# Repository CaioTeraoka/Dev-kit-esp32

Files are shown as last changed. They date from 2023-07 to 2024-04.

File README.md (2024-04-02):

# Dev Kit ESP32
This project is a board that was made with the purpose of being used to create and test simples projects using ESP32 DevKit. It was made to enthusiasts to have a complete board to play and have fun learning about ESP32. 

## Specifications:
**Power** - 5V <br>
**Stackup:**
1. Signal + 3.3V
2. Ground

## Main Components
- ESP32 DevKit <br>
- Buzzer <br>
- LEDs <br>
- Buttons <br>
- RGB LEDs <br>
- SPI Pin Headers <br>
- I2C Pin Headers <br>
- ADC Pin Headers <br>
- DAC Pin Headers <br>
- USART Pin Headers <br>
- PWM Pin Headers <br>

## 3D Model
 <br>


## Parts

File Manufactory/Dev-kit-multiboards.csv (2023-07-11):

Reference | Value | Footprint | LCSC Part Number | Qtd
BUTTON1-BUTTON3 | SW_Push | Button_Switch_SMD:SW_Push_1P1T_NO_6x6mm_H9.5mm | C255812 | 3
BUZZER1 | Buzzer | Buzzer_Beeper:Buzzer_12x9.5RM7.6 | C96222 | 1
C1-C3 | 100n | Capacitor_SMD:C_1206_3216Metric | C377067 | 3
J1, J2 | Conn_01x04_Socket | Connector_PinHeader_2.54mm:PinHeader_1x04_P2.54mm_Vertical | C6332197 | 2
J3, J6, J7, J12, JP1 | -- valores mistos -- | Connector_PinHeader_2.54mm:PinHeader_1x02_P2.54mm_Vertical | C2685144 | 5
J4, J5 | Conn_01x19_Socket | Connector_PinSocket_2.54mm:PinSocket_1x19_P2.54mm_Vertical | C2894942 | 2
J8, J9 | Conn_01x19 | Connector_PinHeader_2.54mm:PinHeader_1x19_P2.54mm_Vertical | C2897382 | 2
J10 | USB_B_Micro | Connector_USB:USB_Micro-B_Molex-105017-0001 | C136000 | 1
LED1, LED2 | LED | LED_SMD:LED_1206_3216Metric | C965822 | 2
R1-R3 | 10k | Resistor_SMD:R_1206_3216Metric | C3018037 | 3
R4, R5 | 300 | Resistor_SMD:R_1206_3216Metric | C104757 | 2
RGB1, RGB2 | WS2812B | WS2812B:WS2812B | C2843785 | 2

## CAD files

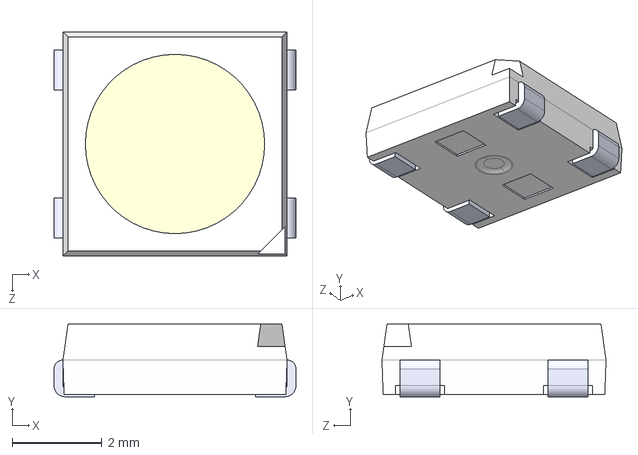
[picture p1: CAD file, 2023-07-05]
Footprints/WS2812B/WS2812B.step
5.40 x 1.62 x 5.00 mm

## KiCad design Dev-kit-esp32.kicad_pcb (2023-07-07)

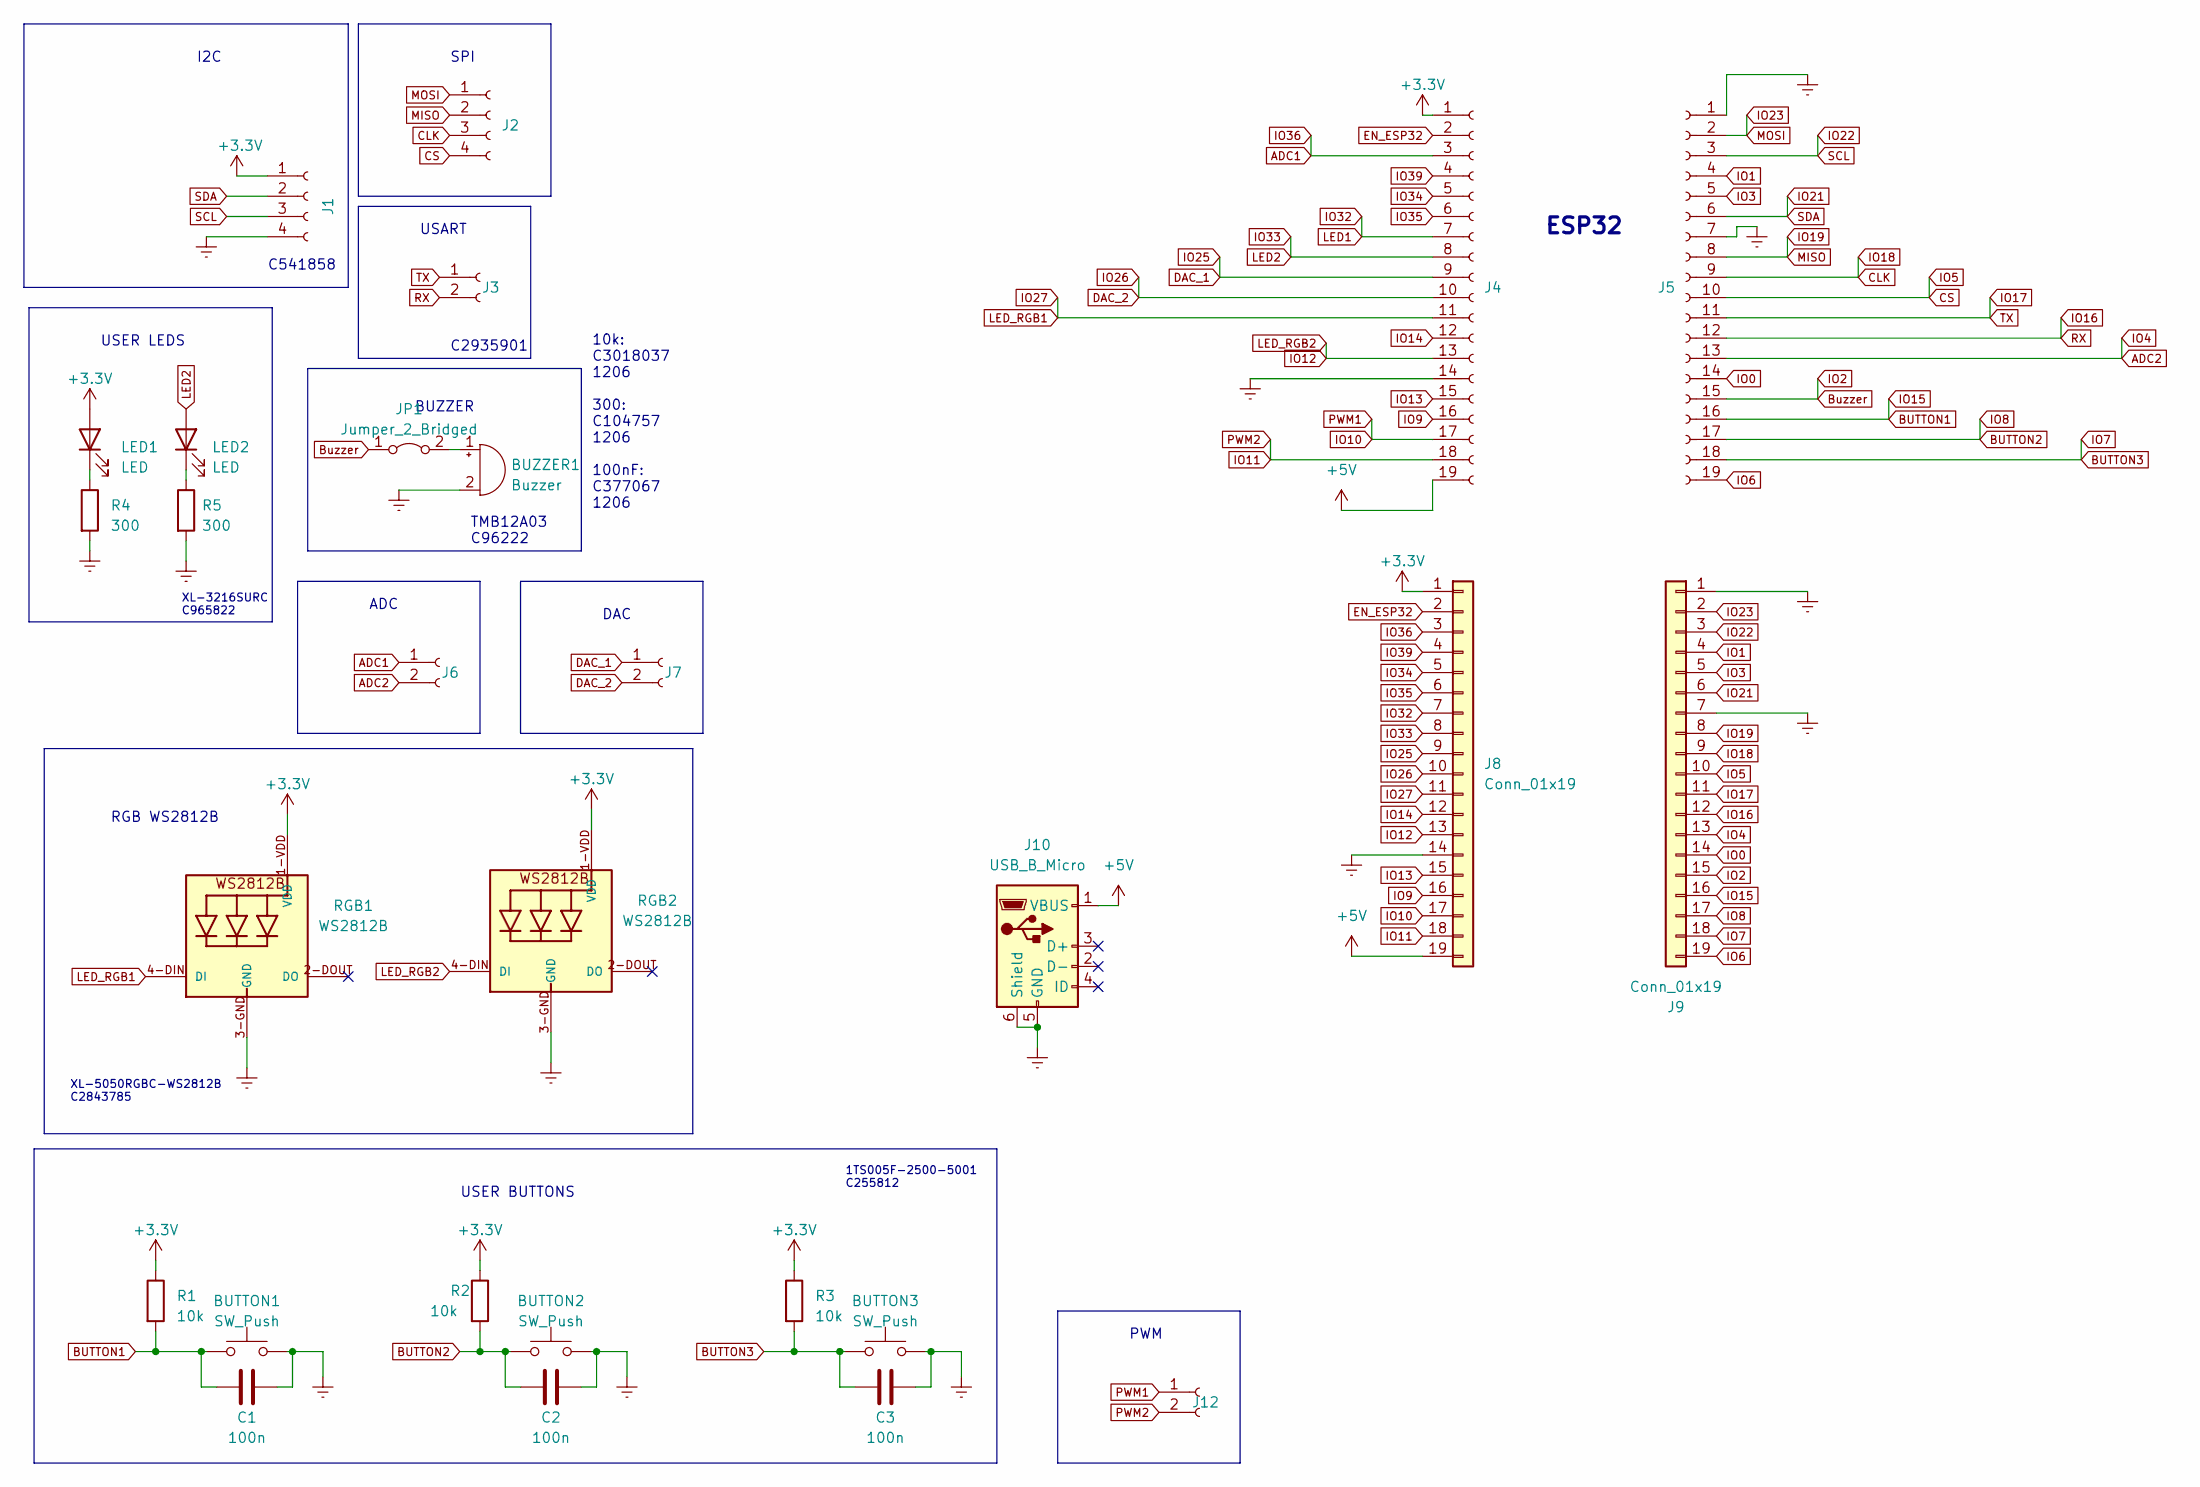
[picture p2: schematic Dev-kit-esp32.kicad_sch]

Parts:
BUTTON1, BUTTON2, BUTTON3: SW_Push; SW_Push_1P1T_NO_6x6mm_H9.5mm; LCSC Part Number C255812
BUZZER1: Buzzer; Buzzer_12x9.5RM7.6; LCSC Part Number C96222
C1, C2, C3: 100n; C_1206_3216Metric; LCSC Part Number C377067
J1, J2: Conn_01x04_Socket; PinHeader_1x04_P2.54mm_Vertical; LCSC Part Number C6332197
J3, J6, J7, J12: Conn_01x02_Socket; PinHeader_1x02_P2.54mm_Vertical; LCSC Part Number C2685144
J4, J5: Conn_01x19_Socket; PinSocket_1x19_P2.54mm_Vertical; LCSC Part Number C2894942
J8, J9: Conn_01x19; PinHeader_1x19_P2.54mm_Vertical; LCSC Part Number C2897382
J10: USB_B_Micro; USB_Micro-B_Molex-105017-0001; LCSC Part Number C136000
JP1: Jumper_2_Bridged; PinHeader_1x02_P2.54mm_Vertical; LCSC Part Number C2685144
LED1, LED2: LED; LED_1206_3216Metric; LCSC Part Number C965822
R1, R2, R3: 10k; R_1206_3216Metric; LCSC Part Number C3018037
R4, R5: 300; R_1206_3216Metric; LCSC Part Number C104757
RGB1, RGB2: WS2812B; LCSC Part Number C2843785

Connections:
+3.3V: J1.1, J4.1, J8.1, LED1.2 (A), R1.1, R2.1, R3.1, RGB1.1-VDD (VDD), RGB2.1-VDD (VDD)
+5V: J4.19, J8.19, J10.1 (VBUS)
ADC1: J4.3, J6.1, J8.3
ADC2: J5.13, J6.2, J9.13
BUTTON1: BUTTON1.1, C1.1, J5.16, J9.16, R1.2
BUTTON2: BUTTON2.1, C2.1, J5.17, J9.17, R2.2
BUTTON3: BUTTON3.1, C3.1, J5.18, J9.18, R3.2
Buzzer: J5.15, J9.15, JP1.1 (A)
CLK: J2.3, J5.9, J9.9
CS: J2.4, J5.10, J9.10
DAC_1: J4.9, J7.1, J8.9
DAC_2: J4.10, J7.2, J8.10
EN_ESP32: J4.2, J8.2
Earth: BUTTON1.2, BUTTON2.2, BUTTON3.2, BUZZER1.2 (+), C1.2, C2.2, C3.2, J1.4, J4.14, J5.1, J5.7, J8.14, J9.1, J9.7, J10.5 (GND), J10.6 (Shield), R4.2, R5.2, RGB1.3-GND (GND), RGB2.3-GND (GND)
IO0: J5.14, J9.14
IO1: J5.4, J9.4
IO3: J5.5, J9.5
IO6: J5.19, J9.19
IO9: J4.16, J8.16
IO10: J4.17, J8.17, J12.1
IO11: J4.18, J8.18, J12.2
IO12: J4.13, J8.13, RGB2.4-DIN (DI)
IO13: J4.15, J8.15
IO14: J4.12, J8.12
IO16: J3.2, J5.12, J9.12
IO17: J3.1, J5.11, J9.11
IO19: J2.2, J5.8, J9.8
IO21: J1.2, J5.6, J9.6
IO22: J1.3, J5.3, J9.3
IO23: J2.1, J5.2, J9.2
IO27: J4.11, J8.11, RGB1.4-DIN (DI)
IO32: J4.7, J8.7
IO33: J4.8, J8.8, LED2.2 (A)
IO34: J4.5, J8.5
IO35: J4.6, J8.6
IO39: J4.4, J8.4
unnamed: BUZZER1.1 (-), JP1.2 (B)
unnamed: LED1.1 (K), R4.1
unnamed: LED2.1 (K), R5.1

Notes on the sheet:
ADC
TMB12A03 C96222
DAC
1TS005F-2500-5001 C255812
SPI
I2C
XL-3216SURC C965822
C541858
USART
PWM
BUZZER
ESP32
C2935901
USER LEDS
XL-5050RGBC-WS2812B C2843785
USER BUTTONS
10k: C3018037 1206 300: C104757 1206 100nF: C377067 1206
RGB WS2812B

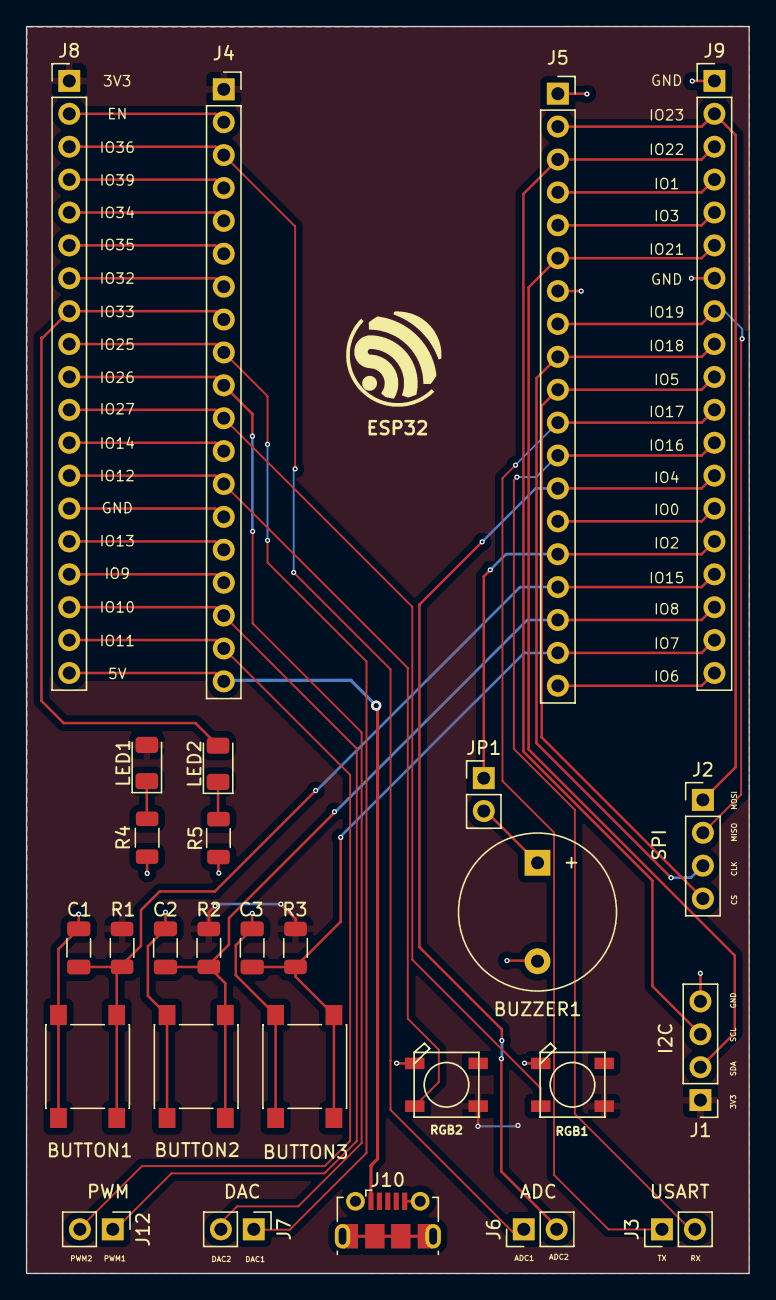
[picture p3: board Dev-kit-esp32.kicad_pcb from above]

Board: 2 copper layers, 55.8 x 96.3 mm, 28 parts (0 on the bottom side), 39 nets.

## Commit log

2023-07-05 Project begin
    [Dev-kit-multiboards.kicad_pcb, Dev-kit-multiboards.kicad_sch, WS2812B.step]
2023-07-05 component placement
    [Dev-kit-multiboards.kicad_pcb, Dev-kit-multiboards.kicad_sch]
2023-07-06 Component placement ESP32
    [Dev-kit-multiboards.kicad_pcb, Dev-kit-multiboards.kicad_sch]
2023-07-07 Final version
    [Dev-kit-multiboards-B_Cu.gbr, Dev-kit-multiboards-B_Mask.gbr, Dev-kit-multiboards-B_Paste.gbr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]
